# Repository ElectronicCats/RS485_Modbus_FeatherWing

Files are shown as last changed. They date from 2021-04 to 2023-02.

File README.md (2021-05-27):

# RS485 Modbus FeatherWing

A Feather board without ambition is a Feather board without FeatherWings! This is a Wing board for the SP3485 RS-485 transceiver IC, which will convert a UART serial stream to RS-485. The SP3485 is a half-duplex transceiver, so it can only communicate one way at a time, but it can reach transmission speeds of up to 10Mbps. This board requires a very low amount of power and can operate from a single +3.3VDC supply.

Works with all Feathers except for those with USB-Serial converters that use the UART pins. Right now that means the ESP8266 Huzzah Feather and nRF52832 Feather don't work.

## Features
- Fully equipped with SP3485 RS-485 transceiver and supporting components
- Operates from a single +3.3V supply
- Interoperable with +5.0V logic
- RS-485 input/output broken out to RJ-45 connector, 3.5mm screw terminal, and 0.1" pitch header
- Driver/Receiver Enable connected to RTS line
- 7V to +12V Common-Mode Input Voltage Range
- Allows up to 32 transceivers on the serial bus
- Driver Output Short-Circuit Protection

Each order comes with one assembled and tested FeatherWing, plus some header. You will need to solder in the header yourself but its a quick task.

## License
OpenSourceLicense

Electronic Cats invests time and resources providing this open source design, please support Electronic Cats and open-source hardware by purchasing products from Electronic Cats!

<a href="https://electroniccats.com/store/">
  
</a>

Designed by Electronic Cats.

Firmware released under an GNU AGPL v3.0 license. See the LICENSE file for more information.

Hardware released under an CERN Open Hardware Licence v1.2. See the LICENSE_HARDWARE file for more information.

Electronic Cats is a registered trademark, please do not use if you sell these PCBs.

27 May 2021

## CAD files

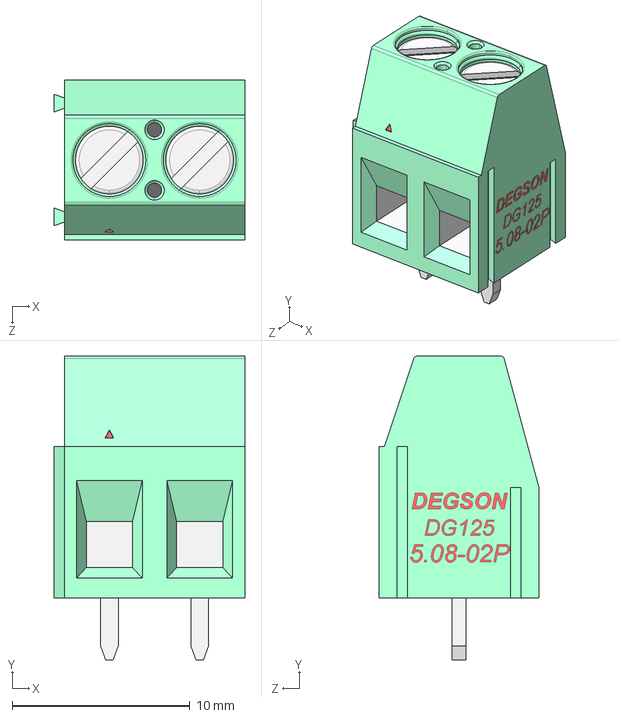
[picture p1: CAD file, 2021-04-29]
Hw/3D_Model/DG125-5.08-02P-14-00AH.STEP
10.7 x 17.1 x 9.00 mm

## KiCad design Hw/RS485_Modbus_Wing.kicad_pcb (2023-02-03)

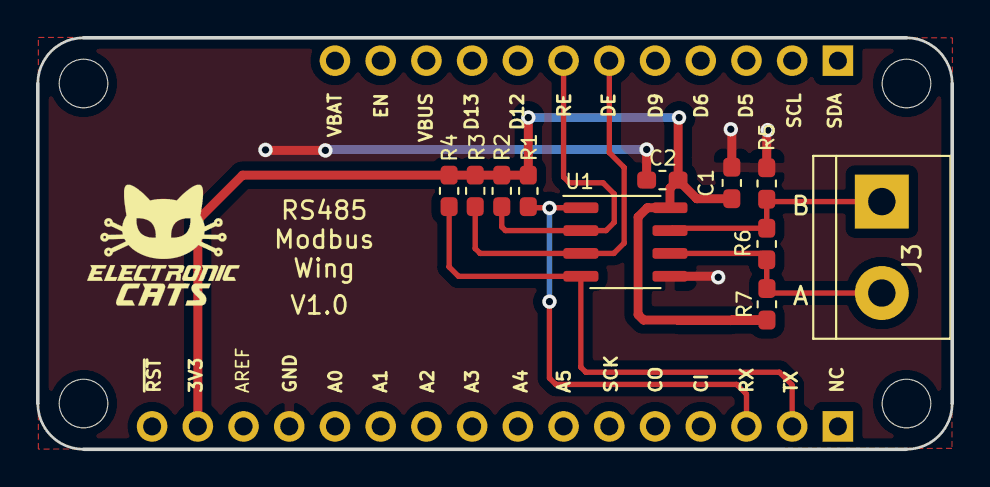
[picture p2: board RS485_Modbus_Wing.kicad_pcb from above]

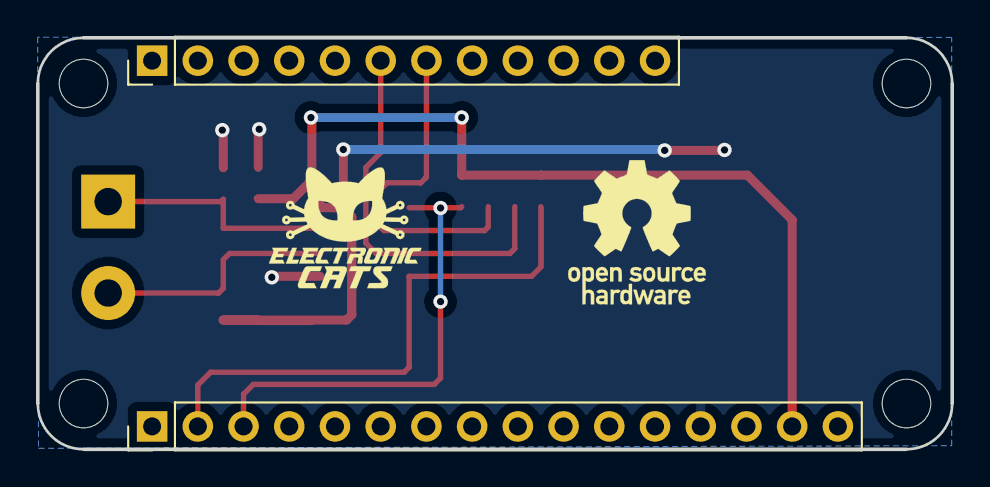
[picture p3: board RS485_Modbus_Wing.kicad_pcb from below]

Board: 2 copper layers, 50.8 x 22.9 mm, 13 parts (2 on the bottom side), 8 nets.

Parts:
C1: 10uF; C_0603_1608Metric_Pad1.05x0.95mm_HandSolder
C2: 0.1uF; C_0603_1608Metric_Pad1.05x0.95mm_HandSolder
J1: feather long; PinHeader_1x16_P2.54mm_Vertical
J2: feather short; PinHeader_1x12_P2.54mm_Vertical
J3: Screw_Terminal_01x02; TerminalBlock_bornier-2_P5.08mm
R1, R2, R3, R4: 10K; R_0603_1608Metric_Pad1.05x0.95mm_HandSolder
R5, R7: 20K; R_0603_1608Metric_Pad1.05x0.95mm_HandSolder
R6: 120; R_0603_1608Metric_Pad1.05x0.95mm_HandSolder
U1: SP3485EN; SOIC-8_3.9x4.9mm_P1.27mm

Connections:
+3V3: C1.1, C2.1, J1.15, R1.1, R2.1, R3.1, R4.1, R7.2, U1.8
/DE: J2.6, R3.2, U1.3
/RE: J2.7, R2.2, U1.2
/RS485A: J3.2, R6.2, R7.1, U1.6
/RS485B: J3.1, R5.2, R6.1, U1.7
/RX: J1.3, R1.2, U1.1
/TX: J1.2, R4.2, U1.4
GND: C1.2, C2.2, J1.13, R5.1, U1.5

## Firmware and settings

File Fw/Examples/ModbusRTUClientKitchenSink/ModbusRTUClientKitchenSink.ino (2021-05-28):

/*
Modbus example

  Andres Sabas @ Electronic Cats
  Original Creation Date: May 27, 2021
  Development environment specifics:

  This code is beerware; if you see me (or any other Electronic Cats
  member) at the local, and you've found our code helpful,
  please buy us a round!
  Distributed as-is; no warranty is given.
*/

#include <ArduinoRS485.h> // ArduinoModbus depends on the ArduinoRS485 library
#include <ArduinoModbus.h>

int counter = 0;

void setup() {
  Serial.begin(9600);
  while (!Serial);

  Serial.println("Modbus RTU Client Kitchen Sink");

  // start the Modbus RTU client
  if (!ModbusRTUClient.begin(9600)) {
    Serial.println("Failed to start Modbus RTU Client!");
    while (1);
  }
}

void loop() {
  writeCoilValues();

  readCoilValues();

  readDiscreteInputValues();

  writeHoldingRegisterValues();

  readHoldingRegisterValues();

  readInputRegisterValues();

  counter++;

  delay(5000);
  Serial.println();
}

void writeCoilValues() {
  // set the coils to 1 when counter is odd
  byte coilValue = ((counter % 2) == 0) ? 0x00 : 0x01;

  Serial.print("Writing Coil values ... ");

  // write 10 Coil values to (slave) id 42, address 0x00
  ModbusRTUClient.beginTransmission(42, COILS, 0x00, 10);
  for (int i = 0; i < 10; i++) {
    ModbusRTUClient.write(coilValue);
  }
  if (!ModbusRTUClient.endTransmission()) {
    Serial.print("failed! ");
    Serial.println(ModbusRTUClient.lastError());
  } else {
    Serial.println("success");
  }

  // Alternatively, to write a single Coil value use:
  // ModbusRTUClient.coilWrite(...)
}

void readCoilValues() {
  Serial.print("Reading Coil values ... ");

  // read 10 Coil values from (slave) id 42, address 0x00
  if (!ModbusRTUClient.requestFrom(42, COILS, 0x00, 10)) {
    Serial.print("failed! ");
    Serial.println(ModbusRTUClient.lastError());
  } else {
    Serial.println("success");

    while (ModbusRTUClient.available()) {
      Serial.print(ModbusRTUClient.read());
      Serial.print(' ');
    }
    Serial.println();
  }

  // Alternatively, to read a single Coil value use:
  // ModbusRTUClient.coilRead(...)
}

void readDiscreteInputValues() {
  Serial.print("Reading Discrete Input values ... ");

  // read 10 Discrete Input values from (slave) id 42, address 0x00
  if (!ModbusRTUClient.requestFrom(42, DISCRETE_INPUTS, 0x00, 10)) {
    Serial.print("failed! ");
    Serial.println(ModbusRTUClient.lastError());
  } else {
    Serial.println("success");

    while (ModbusRTUClient.available()) {
      Serial.print(ModbusRTUClient.read());
      Serial.print(' ');
    }
    Serial.println();
  }

  // Alternatively, to read a single Discrete Input value use:
  // ModbusRTUClient.discreteInputRead(...)
}

void writeHoldingRegisterValues() {
  // set the Holding Register values to counter

  Serial.print("Writing Holding Registers values ... ");

  // write 10 coil values to (slave) id 42, address 0x00
  ModbusRTUClient.beginTransmission(42, HOLDING_REGISTERS, 0x00, 10);
  for (int i = 0; i < 10; i++) {
    ModbusRTUClient.write(counter);
  }
  if (!ModbusRTUClient.endTransmission()) {
    Serial.print("failed! ");
    Serial.println(ModbusRTUClient.lastError());
  } else {
    Serial.println("success");
  }

  // Alternatively, to write a single Holding Register value use:
  // ModbusRTUClient.holdingRegisterWrite(...)
}

void readHoldingRegisterValues() {
  Serial.print("Reading Input Register values ... ");

  // read 10 Input Register values from (slave) id 42, address 0x00
  if (!ModbusRTUClient.requestFrom(42, HOLDING_REGISTERS, 0x00, 10)) {
    Serial.print("failed! ");
    Serial.println(ModbusRTUClient.lastError());
  } else {
    Serial.println("success");

    while (ModbusRTUClient.available()) {
      Serial.print(ModbusRTUClient.read());
      Serial.print(' ');
    }
    Serial.println();
  }

  // Alternatively, to read a single Holding Register value use:
  // ModbusRTUClient.holdingRegisterRead(...)
}

void readInputRegisterValues() {
  Serial.print("Reading input register values ... ");

  // read 10 discrete input values from (slave) id 42,
  if (!ModbusRTUClient.requestFrom(42, INPUT_REGISTERS, 0x00, 10)) {
    Serial.print("failed! ");
    Serial.println(ModbusRTUClient.lastError());
  } else {
    Serial.println("success");

    while (ModbusRTUClient.available()) {
      Serial.print(ModbusRTUClient.read());
      Serial.print(' ');
    }
    Serial.println();
  }

  // Alternatively, to read a single Input Register value use:
  // ModbusRTUClient.inputRegisterRead(...)
}

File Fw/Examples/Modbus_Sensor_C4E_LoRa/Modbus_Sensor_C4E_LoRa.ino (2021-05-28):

/********************************************************************
  Modbus example

  Andres Sabas @ Electronic Cats
  Original Creation Date: May 27, 2021
  Development environment specifics:

  This code is beerware; if you see me (or any other Electronic Cats
  member) at the local, and you've found our code helpful,
  please buy us a round!
  Distributed as-is; no warranty is given.

*********************************************************************/
#include <AqualaboSensors.h>
#include<CayenneLPP.h>
#include <SPI.h>

CayenneLPP lpp(51);

/*!
  We're using a MAX485-compatible RS485 Transceiver.
  Rx/Tx is hooked up to the hardware serial port at 'Serial2'.
  The Data Enable and Receiver Enable pins are hooked up as follows:
*/
#include <lorawan.h>

//ABP Credentials 
const char *devAddr = "26013557";
const char *nwkSKey = "040A022068FB1C137888440CE072ACF0";
const char *appSKey = "3D3E011CBB4CEF72885D12B91C85D680";

const unsigned long interval = 10000;    // 10 s interval to send message
unsigned long previousMillis = 0;  // will store last time message sent
unsigned int counter = 0;     // message counter

char myStr[50];
char outStr[255];
byte recvStatus = 0;

const sRFM_pins RFM_pins = {
  .CS = SS,
  .RST = RFM_RST,
  .DIO0 = RFM_DIO0,
  .DIO1 = RFM_DIO1,
  .DIO2 = RFM_DIO2,
  .DIO5 = RFM_DIO5,
};
// instantiate aqualaboModbusSensors object
aqualaboModbusSensorsClass aqualaboModbusSensors;

void setup() {
  Serial.begin(9600);

  
  
  while (!Serial);
  Serial.println("Modbus Sensor C4E");
  
  if(!lora.init()){
    Serial.println("RFM95 not detected");
    delay(5000);
    return;
  }
    pinMode(RFM_TCX_ON,OUTPUT);
    pinMode(RFM_SWITCH,OUTPUT);
    pinMode(LED_BUILTIN,OUTPUT);

  // Set LoRaWAN Class change CLASS_A or CLASS_C
  lora.setDeviceClass(CLASS_A);

  // Set Data Rate
  lora.setDataRate(SF8BW125);

  // set channel to random
  lora.setChannel(MULTI);
  
  // Put ABP Key and DevAddress here
  lora.setNwkSKey(nwkSKey);
  lora.setAppSKey(appSKey);
  lora.setDevAddr(devAddr);
// Modbus communication runs at 9600 baud
  Serial1.begin(9600);
  //Modbus slave ID 1, pin De, Pin Re, Serial
  aqualaboModbusSensors.begin(30, 11, 10, Serial1 );
  
  // Setups the sensor configuration paramenters 
  Serial.println("Init sensor");
  aqualaboModbusSensors.initSensor();
  
  Serial.println("Ready... ");
}

void loop() {
  
  // Reads the sensor data
  aqualaboModbusSensors.read();

  // Variable: stores measured temperature in Celsius degrees
  Serial.print("Temperature: ");
  Serial.println(aqualaboModbusSensors.sensorC4E.temperature, 2);
  
  // Variable: stores measured conductivity in μS/cm
  Serial.print("Conductivity: ");
  Serial.println(aqualaboModbusSensors.sensorC4E.conductivity, 2);
  
  
 if(millis() - previousMillis > interval) {
     previousMillis = millis();

     Serial.print("Sending: ");
     printVariables();

     lora.sendUplink((char *)lpp.getBuffer(), lpp.getSize(), 0, 1);
    }

    recvStatus = lora.readData(outStr);
    if(recvStatus) {
     Serial.println("Received: ");
     Serial.println(outStr);
    }
  
  // Check Lora RX
  lora.update();
}

void printVariables()
{
  lpp.reset();

  int humidity = aqualaboModbusSensors.sensorC4E.conductivity;
  Serial.print(F("conductivity="));
  Serial.print(humidity, 2);
  lpp.addRelativeHumidity(3, humidity);

  int temp = aqualaboModbusSensors.sensorC4E.temperature;
  Serial.print(F(", Tempetarure="));
  Serial.print(temp, 2);
  lpp.addTemperature(4, temp);


}

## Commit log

2020-11-10 fix labels and logos
    [RS485_Modbus_Wing.kicad_pcb]
2020-11-30 fix layout
    [RS485_Modbus_Wing.kicad_pcb, RS485_Modbus_Wing.sch]
2020-12-01 add solder mask clearence
    [RS485_Modbus_Wing.kicad_pcb]
2023-01-23 BOM update and generated
    [RS485_Modbus_Wing.kicad_sch]
